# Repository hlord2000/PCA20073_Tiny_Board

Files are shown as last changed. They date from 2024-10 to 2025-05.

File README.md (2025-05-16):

# PCA20073 Tiny Board - nRF54L15 Coin Cell Board 
A very small demo board showing the solution size of Nordic's nRF54L15 in chip-scale package.
Alongside our components are our partners' products: **SiTime's** <0.5x0.5mm MEMS resonator, **Ignion's** 3x2mm 2.4G-10.6Hz chip antenna, **Analog Device's** new micropower 3-axis accelerometer

<p align="center">
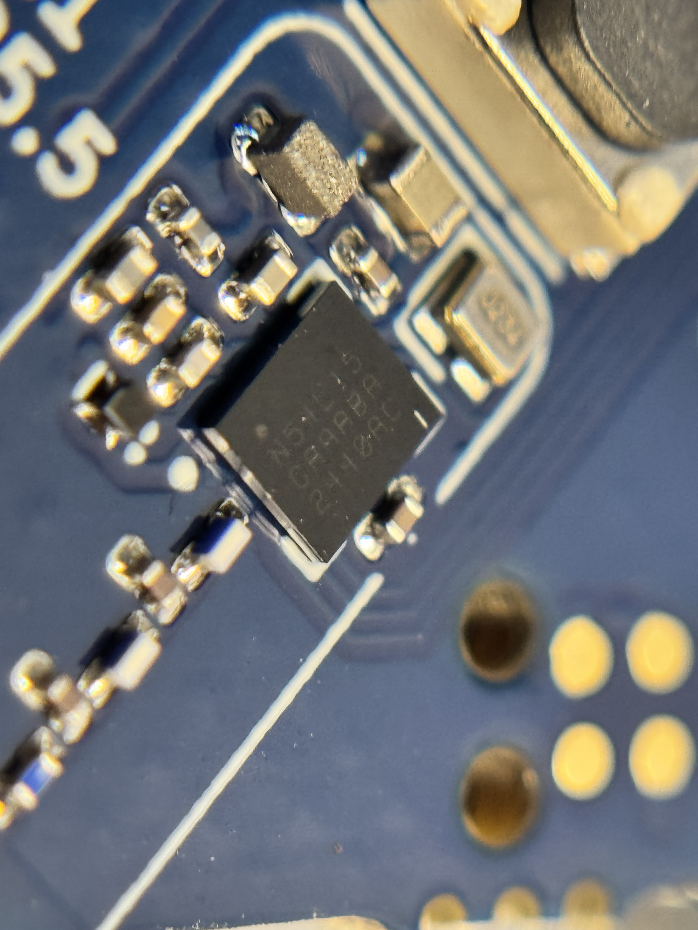
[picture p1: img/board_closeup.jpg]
    
</p>

<p align="center">
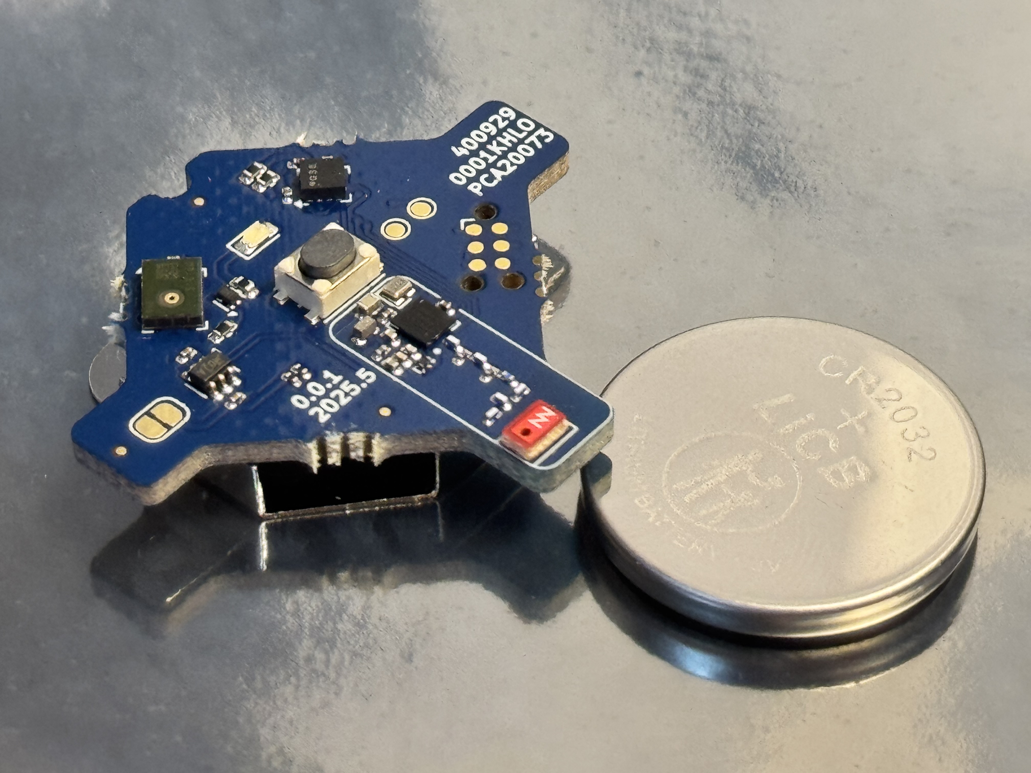
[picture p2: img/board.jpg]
    
</p>

## Key components

| Reference Designator | Part Number | Description |
|---|---|---|
| U1 | nRF54L15-CAAA | [Nordic Semiconductor nRF54L15 Series - Advanced multiprotocol System-on-Chip (SoC) supporting Bluetooth Low Energy, ANT, 802.15.4, Thread, Zigbee, and proprietary 2.4 GHz protocols.](https://www.nordicsemi.com/Products/nRF54L15) |
| Y2 | SiT11100-A6-032.0000-E6035-T325 | [SiTime ultra-small 0505 Size 32 MHz MEMS Resonator](https://www.sitime.com/products/mems-resonators/sit11100) |
| AE1 | NN02-101 | [Ignion NANO mXTEND - Ultra-small 2.4GHz chip antenna utilizing Virtual Antenna® technology.](https://ignion.io/product/nano-mxtend/) |
| U3 | ADXL366 | [Analog Devices ADXL366 - Micropower, 3-Axis, ±2g/±4g/±8g Digital Output MEMS Accelerometer.](https://www.analog.com/en/products/adxl366.html) |

## System Features
- Low Vf blue LED for indication
- Tag-Connect TC2030 for debug port
- UART TX/RX pads for testing
- Jumper for system power characterization using the [PPK2](https://www.nordicsemi.com/Products/Development-hardware/Power-Profiler-Kit-2)

## Possible Usecases
- BLE Beacon
- Channel sounding reflector

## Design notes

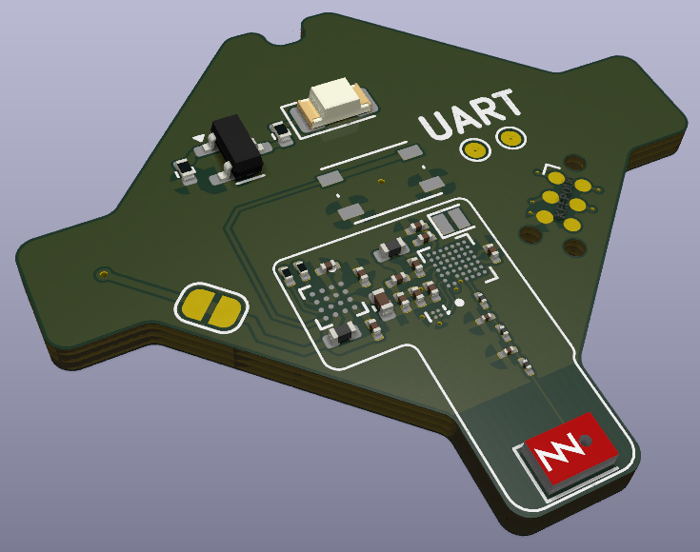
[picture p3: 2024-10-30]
production/PCA20073_Tiny_Board_Single/img/board.png

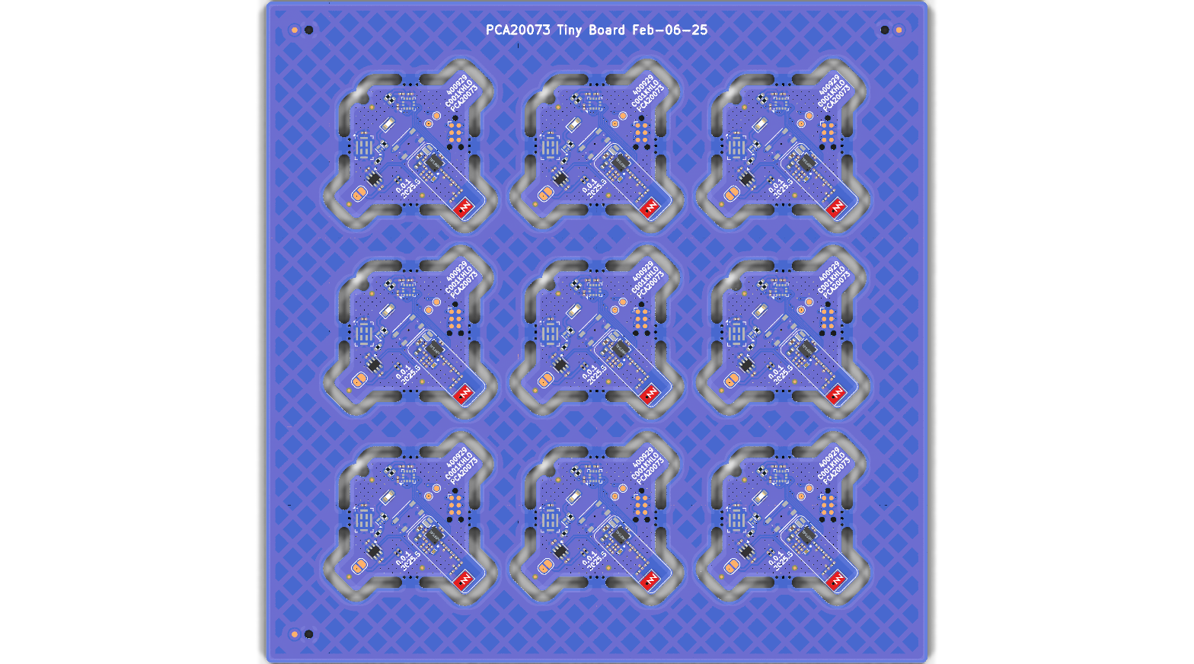
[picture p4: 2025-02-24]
production/PCA20073_Tiny_Board_Panel/PCA20073_Tiny_Board_Panel.kicad_pcb.png

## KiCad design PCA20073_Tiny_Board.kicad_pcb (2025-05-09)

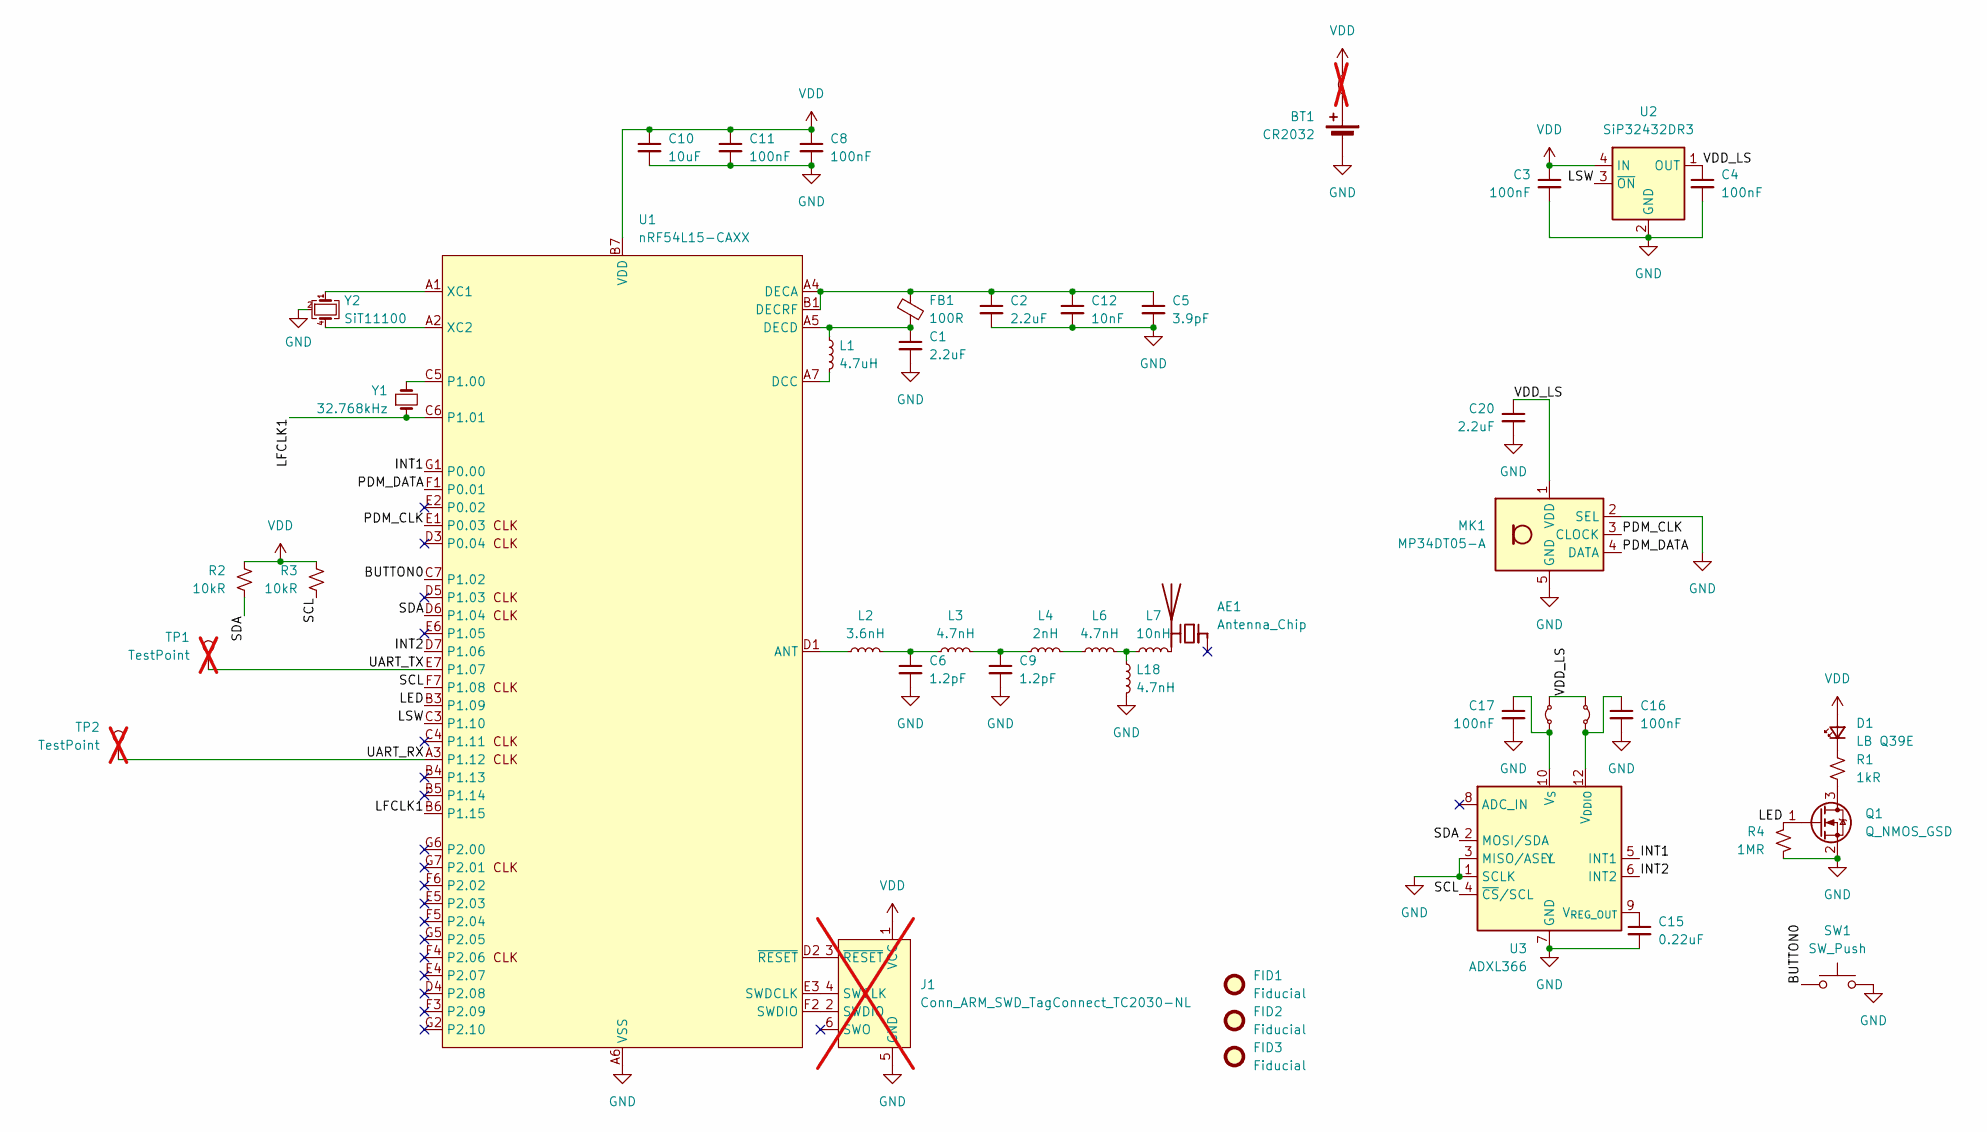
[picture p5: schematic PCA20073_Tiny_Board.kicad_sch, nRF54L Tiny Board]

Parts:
AE1: Antenna_Chip; Ignion_NN02-101; PartId 100700079
BT1: CR2032; BatteryHolder_Multicomp_BC-2001_1x2032; PartId 100500047; LCSC C964829
C1, C2, C20: 2.2uF; C_0201_0603Metric; PartId 100200660; LCSC C23630
C3, C4, C8, C11, C16, C17: 100nF; C_0201_0603Metric; PartId 100200469; LCSC C76939
C5: 3.9pF; C_0201_0603Metric; PartId 100200424; LCSC C22374845
C6, C9: 1.2pF; C_0201_0603Metric; PartId 100200086; LCSC C85895
C10: 10uF; C_0402_1005Metric; PartId 100200383; LCSC C15525
C12: 10nF; C_0201_0603Metric; PartId 100200491; LCSC C76941
C15: 0.22uF; C_0201_0603Metric; PartId 100200487; LCSC C701263
D1: LB Q39E; LED_0603_1608Metric; PartId 101400142; LCSC C84273
FB1: 100R; C_0201_0603Metric; PartId 100300419; LCSC C83991
FID1, FID2, FID3: Fiducial; Fiducial_0.5mm_Mask1mm
J1: Conn_ARM_SWD_TagConnect_TC2030-NL; Tag-Connect_TC2030-IDC-NL_2x03_P1.27mm_Vertical; not fitted
JP1: Jumper_2_Small_Bridged; SolderJumper-2_P1.3mm_Bridged_RoundedPad1.0x1.5mm; not fitted
JP2, JP3: Jumper_2_Small_Bridged; R_0402_1005Metric; PartId 100100109; LCSC C17168
L1: 4.7uH; L_0402_1005Metric; PartId 100300441
L2: 3.6nH; L_0201_0603Metric; PartId 100300223; LCSC C275212
L3, L6, L18: 4.7nH; L_0201_0603Metric; PartId 100300231; LCSC C86126
L4: 2nH; L_0201_0603Metric; PartId 100300016; LCSC C307709
L7: 10nH; L_0201_0603Metric; PartId 100300242; LCSC C162594
MK1: MP34DT05-A; ST_HCLGA-4_3x4mm_P1.35mm; PartId MP34DT05-A
Q1: Q_NMOS_GSD; Diodes_DFN1006-3; PartId 101300187; LCSC C7527987
R1: 1kR; R_0402_1005Metric; PartId 100100171; LCSC C106235
R2, R3: 10kR; R_0201_0603Metric; PartId 100100065; LCSC C106225
R4: 1MR; R_0402_1005Metric; PartId 100100265; LCSC C138033
SW1: SW_Push; SW_Push_1P1T_NO_Vertical_Wuerth_434133025816; PartId 101500104; LCSC C127488
TP1, TP2: TestPoint; TestPoint_Pad_D1.0mm; not fitted
U1: nRF54L15-CAXX; BGA-47_7x7_2.451x2.245mm; PartId 102000283
U2: SiP32432DR3; SOT-363_SC-70-6; PartId SiP32432DR3; LCSC C141606
U3: ADXL366; Analog_LGA-12_2.20x2.30mm_P0.5mm; PartId ADXL366
Y1: 32.768kHz; Crystal_SMD_1210-2Pin_1.2x1.0mm; PartId ECS-.327-9-1210-TR
Y2: SiT11100; Oscillator_SMD_SiTime_SiT11100-4Pin_0.46x0.46mm; PartId SiT11100

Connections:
/BUTTON0: SW1.1, U1.C7 (P1.02)
/INT1: U1.G1 (P0.00), U3.5 (INT1)
/INT2: U1.D7 (P1.06), U3.6 (INT2)
/LED: Q1.1 (G), R4.1, U1.B3 (P1.09)
/LFCLK1: U1.B6 (P1.15), U1.C6 (P1.01), Y1.1
/LSW: U1.C3 (P1.10), U2.3 (~ON)
/PDM_CLK: MK1.3 (CLOCK), U1.E1 (P0.03)
/PDM_DATA: MK1.4 (DATA), U1.F1 (P0.01)
/SCL: R3.2, U1.F7 (P1.08), U3.4 (~CS/SCL)
/SDA: R2.2, U1.D6 (P1.04), U3.2 (MOSI/SDA)
/UART_RX: TP2.1, U1.A3 (P1.12)
/UART_TX: TP1.1, U1.E7 (P1.07)
/VDD_LS: C4.1, C20.1, JP2.2 (B), JP3.2 (B), MK1.1 (VDD), U2.1 (OUT)
GND: BT1.2 (-), C1.2, C2.2, C3.2, C4.2, C5.2, C6.2, C8.2, C9.2, C10.2, C11.2, C12.2, C15.2, C16.2, C17.2, C20.2, J1.5 (GND), L18.2, MK1.2 (SEL), MK1.5 (GND), Q1.2 (S), R4.2, SW1.2, U1.A6 (VSS), U1.C2 (VSS_PA), U1.G4 (VSS), U2.2 (GND), U2.5 (GND), U3.1 (SCLK), U3.3 (MISO/ASEL), U3.7 (GND), U3.11 (GND), Y2.2, Y2.3
unnamed: AE1.2 (PCB_Trace), L7.2
unnamed: BT1.1 (+), JP1.1 (A)
unnamed: C6.1, L2.2, L3.1
unnamed: C9.1, L3.2, L4.1
unnamed: D1.1 (K), R1.1
unnamed: J1.4 (SWCLK), U1.E3 (SWDCLK)
unnamed: J1.2 (SWDIO), U1.F2 (SWDIO)
unnamed: J1.3 (~RESET), U1.D2 (~RESET)
unnamed: C16.1, JP2.1 (A), U3.12 (V_{DDIO})
unnamed: C17.1, JP3.1 (A), U3.10 (V_{S})
unnamed: L4.2, L6.1
unnamed: L6.2, L7.1, L18.1
unnamed: Q1.3 (D), R1.2
unnamed: L2.1, U1.D1 (ANT)
unnamed: L1.2, U1.A7 (DCC)
unnamed: C2.1, C5.1, C12.1, FB1.1, U1.A4 (DECA), U1.B1 (DECRF)
unnamed: C1.1, FB1.2, L1.1, U1.A5 (DECD)
unnamed: U1.C5 (P1.00), Y1.2
unnamed: U1.A1 (XC1), Y2.1
unnamed: U1.A2 (XC2), Y2.4
unnamed: C15.1, U3.9 (V_{REG_OUT})
VDD: C3.1, C8.1, C10.1, C11.1, D1.2 (A), J1.1 (VCC), JP1.2 (B), R2.1, R3.1, U1.B7 (VDD), U1.G3 (VDD), U2.4 (IN)

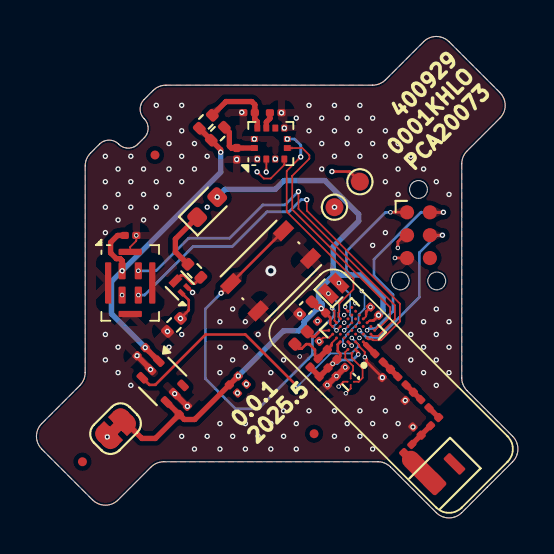
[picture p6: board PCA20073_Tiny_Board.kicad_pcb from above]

Board: 4 copper layers, 26.7 x 26.7 mm, 47 parts (1 on the bottom side), 36 nets.

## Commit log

2024-10-29 Initial commit.
    [nRF54L15_nPM2100_CR2032.kicad_pcb, nRF54L15_nPM2100_CR2032.kicad_sch]
2024-10-30 Routing complete
    [nRF54L15_nPM2100_CR2032.kicad_pcb, nRF54L15_nPM2100_CR2032.kicad_sch]
2024-11-07 Nov. 7th 2024
    [nRF54L15_nPM2100_CR2032-B_Cu.gbr, nRF54L15_nPM2100_CR2032-B_Mask.gbr, nRF54L15_nPM2100_CR2032-B_Paste.gbr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]
2024-12-24 Update Dec. 24
    [nRF54L15_nPM2100_CR2032.kicad_pcb]
2025-01-31 Updated for production
    [nRF54L15_nPM2100_CR2032.kicad_pcb, nRF54L15_nPM2100_CR2032.kicad_sch, nRF54L15_nPM2100_CR2032.step]
2025-01-31 Added production panel files
    [PCA20073_nRF54L15_Tiny_Board-B_Courtyard.gbr, PCA20073_nRF54L15_Tiny_Board-B_Cu.gbl, PCA20073_nRF54L15_Tiny_Board-B_Fab.gbr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]
2025-01-31 Added panel jan 31 2025
    [PCA20073_nRF54L15_Tiny_Board-B_Courtyard.gbr, PCA20073_nRF54L15_Tiny_Board-B_Cu.gbl, PCA20073_nRF54L15_Tiny_Board-B_Fab.gbr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]
2025-02-03 Fixed issues w/ mousebites, added stitching vias, added fiducials
    [nRF54L15_nPM2100_CR2032.kicad_pcb, nRF54L15_nPM2100_CR2032.kicad_sch, nRF54L15_nPM2100_CR2032.step]
2025-02-24 Added latest production files
    [PCA20073_Tiny_Board-B_Adhesive.gbr, PCA20073_Tiny_Board-B_Cu.gbr, PCA20073_Tiny_Board-B_Fab.gbr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]
2025-05-09 Reworked SiT11100 footprint
    [PCA20073_Tiny_Board.kicad_pcb, PCA20073_Tiny_Board.kicad_sch]
